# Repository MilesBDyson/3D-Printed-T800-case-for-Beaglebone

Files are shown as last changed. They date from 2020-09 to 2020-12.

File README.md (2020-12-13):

The STL files were originally downloaded from somewhere on Thingiverse. I used blender to modify them for
mounting a Beaglebone Black inside the head, I hand drilled 3 holse for the user leds in each temple,
the holse for the eyes are ruffly 3mm, so if you want to use the bigger 5mm LED's like i have you will
need to open them up.

the 4 hols between the top and middle pieces of the head are for pins so you can remove the top allowing access
to the Beaglebone, also there is room to moune a 50 x 50 x 15 12v fan wich will be activated by a relay

the bolt patern for the beaglebone was marked holding the Beaglebone in place, then installing 3/8 inch plastic
standoffs on the Beaglebone, I drilled the holes and dry fitted everything to be sure the standoffs fit nicely
(had to open up a few of them).

I applied a liberal amount of model glue to them and installed the Beaglebone, allowing several hours for the
glue to dry before removing the Beaglebone, I applied more glue making sure the standoffs were firmly fixed in
place.

This project is not perfect and it did require a lot of hand work to clean everything up nicely but my patience
payed off. How I moved the User LED's to GPIO pins is documented with a step by step guide as it was not for
the beginner and requires modifying and compiling a few files along with creating an overlay wich will free up
the pins to be used used. 

<b>Warining</b>: the user led's pins can not be used to light up a LED directly, you will damage your Beaglebone, You
will need to use an IC chip like ULN2003 to lite the LED's for you, also mentioned in the documents for moving
the User LED's to GPIO pins.

<b>Update:</b> i decided to holow out the eyes with a dremel and printed a translusent red lens to cover the LED's in the eyes.

Initial Print
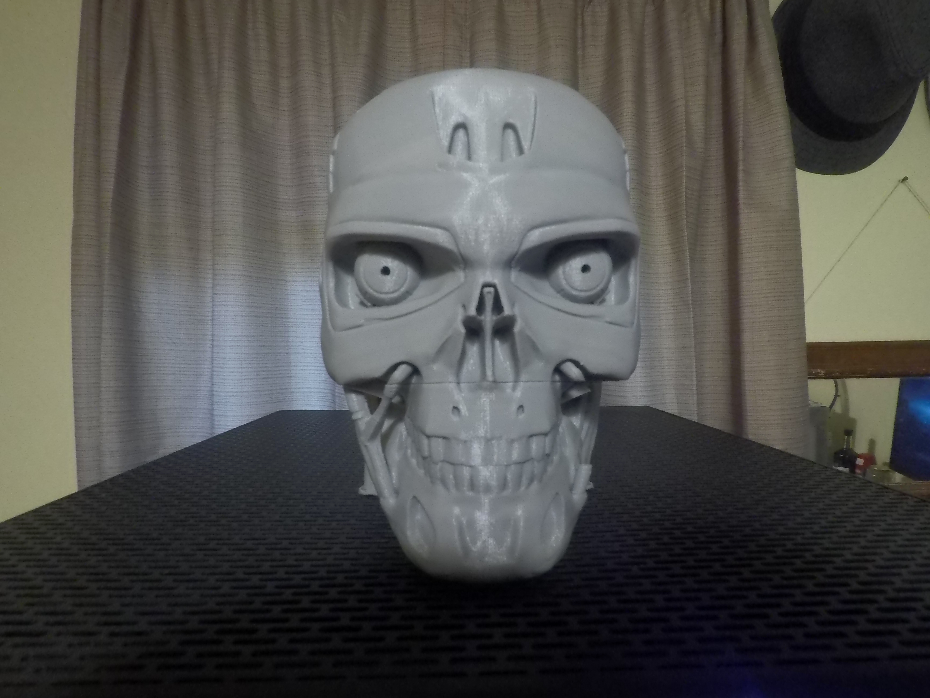
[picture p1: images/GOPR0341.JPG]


Chrome spaypaint (not relly chrome) for base color
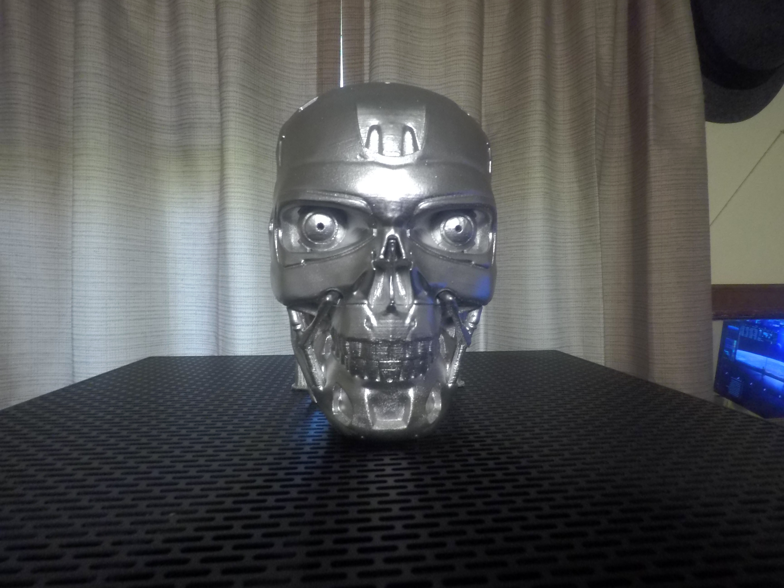
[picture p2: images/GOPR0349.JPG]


After Antiquing
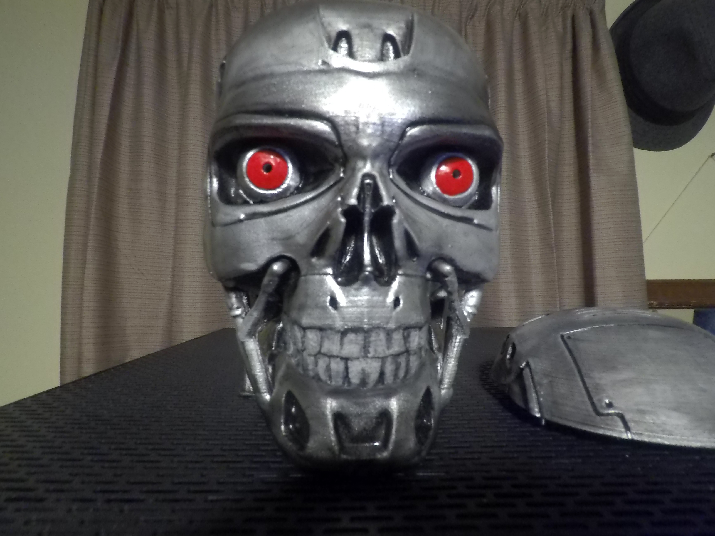
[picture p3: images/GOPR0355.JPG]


Close up of holes in the temples for User LEDS from the BBB
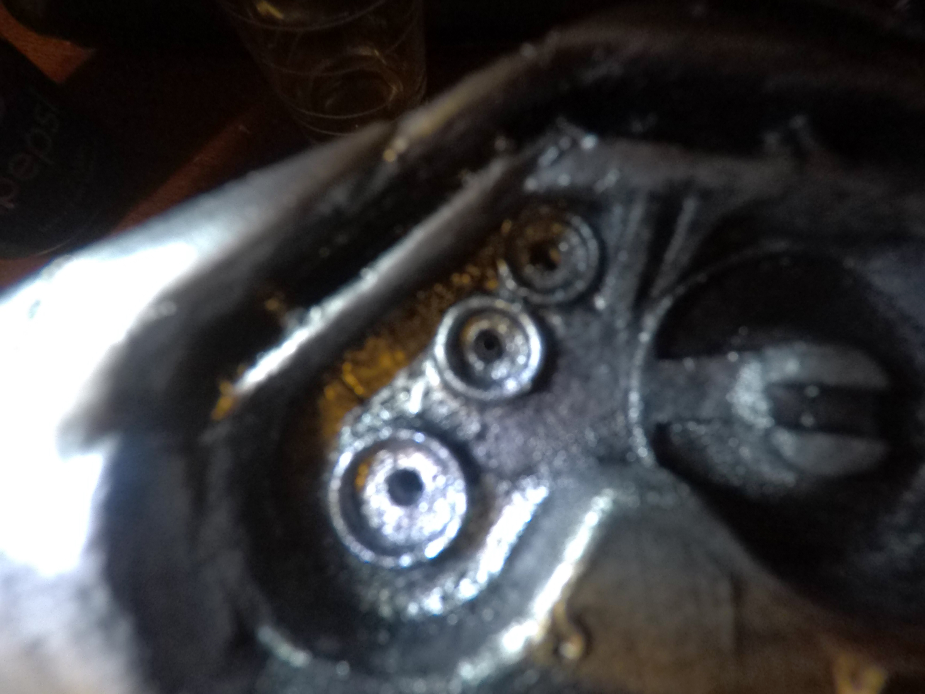
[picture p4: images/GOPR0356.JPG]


Beaglebone Mounted inside the head
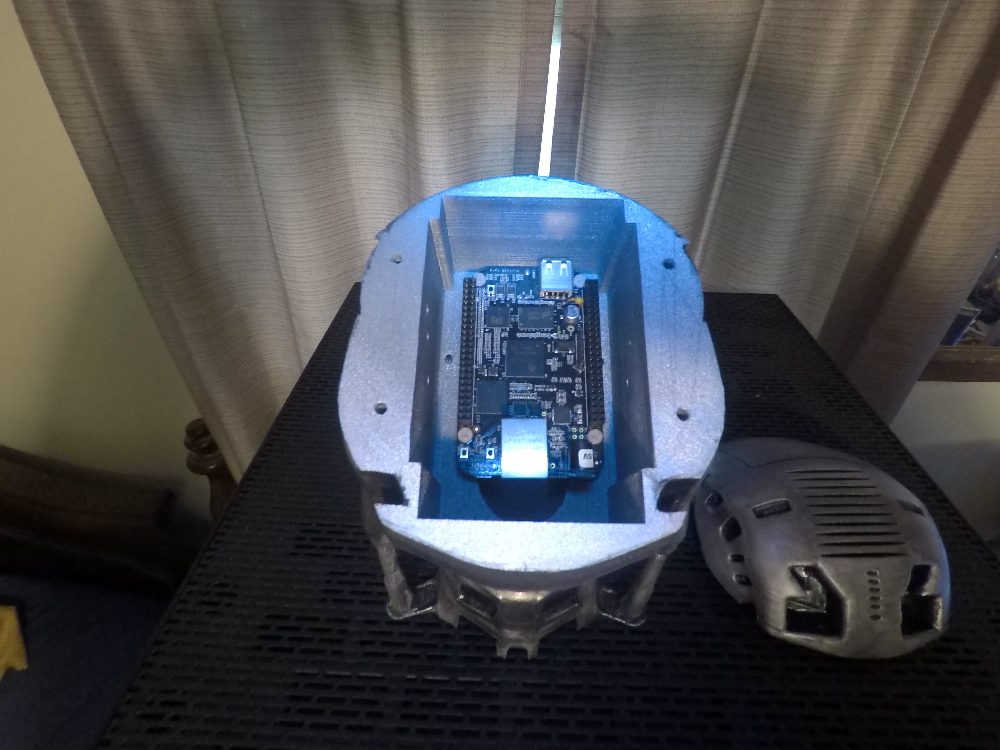
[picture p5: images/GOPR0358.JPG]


Finished result after modifying the eyss with translucent lenses
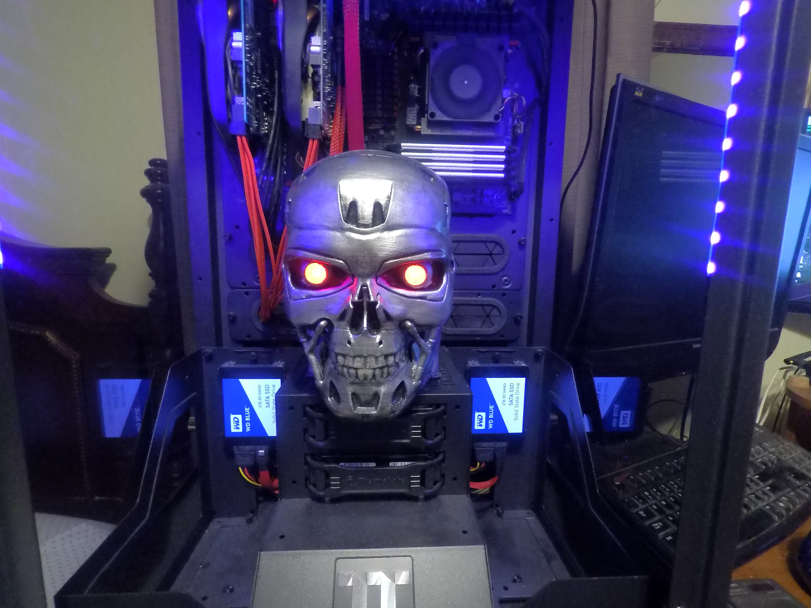
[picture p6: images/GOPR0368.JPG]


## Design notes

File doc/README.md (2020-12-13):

This folder contains instructions and a few charts on how i moved the User LED's to external pins on the Beaglebone Black to be mounted in the templs of the skull

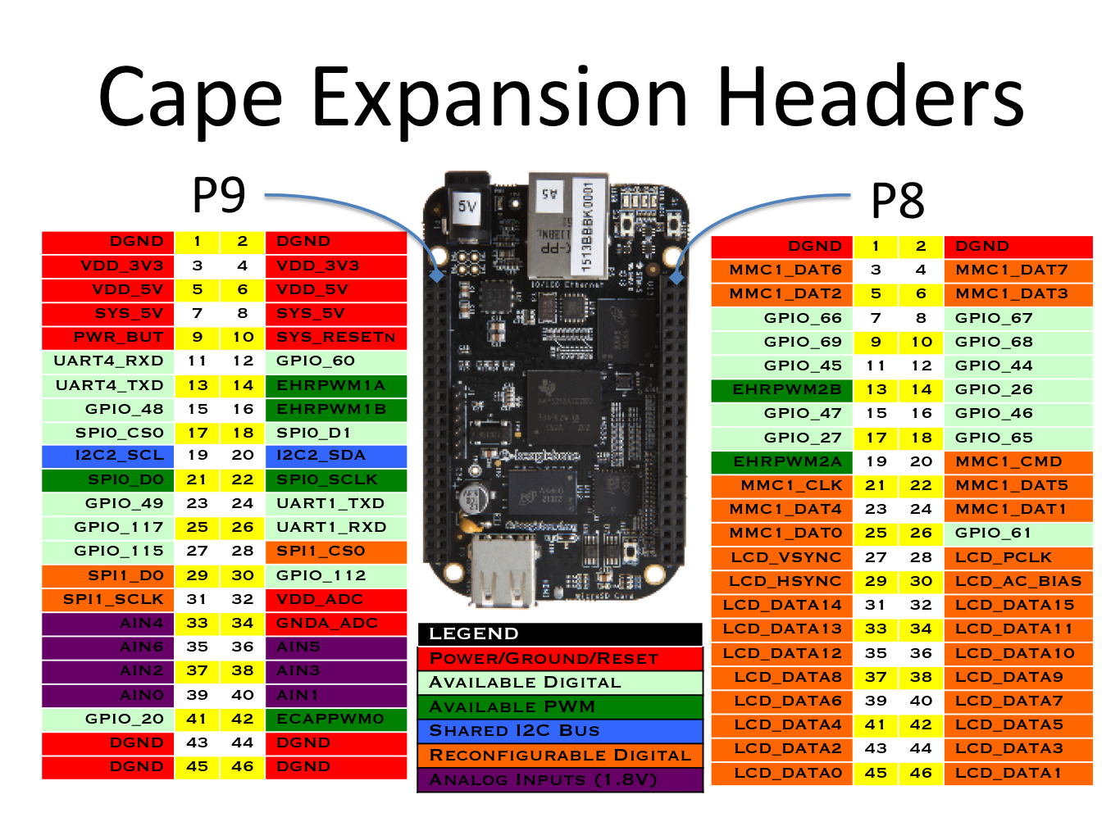
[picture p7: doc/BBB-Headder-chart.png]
T800


P8Header

P9Header

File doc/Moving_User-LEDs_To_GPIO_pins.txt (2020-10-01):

Remaping the User LED's to GPIO pins on the BeagleBone Black running Ubuntu Server 18.04 or Newer.

If you have not setup your Beaglebone Black Rev. C yet, you may want to refer to

https://rcn-ee.com/rootfs/2020-04-09/flasher/ 

This is the newest release at the time of writing this guide. for the latest Ubuntu Server Image you may want to check by navigating
up one level and make sure you are in the newest release directory where you can download and copy to your microSD card that you
can install directly to your onboard eMMC. This guide was only tested on Ubuntu but may be the same for Debian also availble there.

Wiring the circuit for the Leds.

Remember you should allways wire your circuit with the Beaglebone Powered Down. You may damage your Beaglebone if you attempt to
wire up a circuit with it powered ON.

you will need 4 leds with 4 470ohm resistors and 1 ULN2003A 16-pin Dip, a breadboard will be ideal for setting it all up as you
can get things working first then move the circuit as needed to a circuitboard to be soldered for a more perminant setup.

            ULN2003A                       LED                    Resistor
             __ __
   1    1B--|  U  |--1C    9
   2    2B--|     |--2C    10              ___
   3    3B--|     |--3C    11             |   |                   -------
   4    4B--|     |--4C    12             |   |          ---------| 470 |---------
   5    5B--|     |--5C    13            -------                  -------
   6    6B--|     |--6C    14              | |
   7    7B--|     |--7C    15              | | Neg
   8   GND--|_____|--VCC   16          Pos |  

Make your connections from your Beaglebone GPIO pins to the 'B' side of the ULN2003A IC chip.
Then make your connecitons from the ULN2003A IC Chip 'C' side to your LED's Negative side.

   --------------------------------------------
   | Headder | IC Pin |  IC  | IC Pin |  LED  |
   --------------------------------------------
   |  P8_8   |   1B   |      |   1C   |  Neg  |
   |  P8_10  |   2B   |      |   2C   |  Neg  |
   |  P8_12  |   3B   |      |   3C   |  Neg  |
   |  P8_14  |   4B   |      |   4C   |  Neg  |
   --------------------------------------------

Now i recommend using an external power source for most projects as to not worry about overloading the Beaglebone, so
if you do use an external power sourece be sure to share the ground of your Beaglebone with the power soruce or the
circuit will not work.

beaglebone ground ----------\
                             -----> IC Chip Ground (pin 8)                 
external power ground-------/

external power positive ------470ohm resistor-------Pos leg of LED

'C' side of IC Chip---------------------------------Neg leg of LED

Remaping the User LED's

1.) Make Backup
SSH into your Beaglebone and create a backup of the file your about to edit just in case, its allways best to have a backup.

$ sudo cp /opt/source/dtb-4.14-ti/src/arm/am335x-bone-common.dtsi /opt/source/dtb-4.14-ti/src/arm/am335x-bone-common.dtsi.backup

2.) remap user LED's to the GPIO pins
Edit the file to move the User LED's to the GPIO pins of your choice or you may use the same ones i did in this guide.

$ sudo nano /opt/source/dtb-4.14-ti/src/arm/am335x-bone-common.dtsi

make your file look similar to this, you will find this section near the top of the file, you will need to refer to the headder
tables, also included in the doc folder and get the mode7 (column) information, depending on what pins you choose. 

comment out with "//" the original lines and add new ones containing your pin information, incase you wish to undo this later.
I am using pins from the P8 Hedder pins 8,10,12 and 14

                led2 {
                        label = "beaglebone:green:usr0";
//                      gpios = <&gpio1 21 GPIO_ACTIVE_HIGH>;
                        gpios = <&gpio2 3 GPIO_ACTIVE_HIGH>;            /* P8_8  */
                        linux,default-trigger = "heartbeat";
                        default-state = "off";
                };

                led3 {
                        label = "beaglebone:green:usr1";
//                      gpios = <&gpio1 22 GPIO_ACTIVE_HIGH>;
                        gpios = <&gpio2 4 GPIO_ACTIVE_HIGH>;            /* P8_10 */
                        linux,default-trigger = "mmc0";
                        default-state = "off";
                };

                led4 {
                        label = "beaglebone:green:usr2";
//                      gpios = <&gpio1 23 GPIO_ACTIVE_HIGH>;
                        gpios = <&gpio1 12 GPIO_ACTIVE_HIGH>;           /* P8_12 */
                        linux,default-trigger = "cpu0";
                        default-state = "off";
                };

                led5 {
                        label = "beaglebone:green:usr3";
//                      gpios = <&gpio1 24 GPIO_ACTIVE_HIGH>;
                        gpios = <&gpio0 26 GPIO_ACTIVE_HIGH>;           /* P8_14 */
                        linux,default-trigger = "mmc1";
                        default-state = "off";
                };

refer to the header tables for correct address/offset (column) of the pins you are using, this will be a Hexadecimal number.

        user_leds_s0: user_leds_s0 {
                pinctrl-single,pins = <
//                      AM33XX_PADCONF(AM335X_PIN_GPMC_A5, PIN_OUTPUT_PULLDOWN, MUX_MODE7)      /* gpmc_a5.gpio1_21 */
//                      AM33XX_PADCONF(AM335X_PIN_GPMC_A6, PIN_OUTPUT_PULLUP, MUX_MODE7)        /* gpmc_a6.gpio1_22 */
//                      AM33XX_PADCONF(AM335X_PIN_GPMC_A7, PIN_OUTPUT_PULLDOWN, MUX_MODE7)      /* gpmc_a7.gpio1_23 */
//                      AM33XX_PADCONF(AM335X_PIN_GPMC_A8, PIN_OUTPUT_PULLUP, MUX_MODE7)        /* gpmc_a8.gpio1_24 */
                        AM33XX_PADCONF(0x894, PIN_OUTPUT_PULLDOWN, MUX_MODE7)      /* P8_8  */
                        AM33XX_PADCONF(0x898, PIN_OUTPUT_PULLUP, MUX_MODE7)        /* P8_10 */
                        AM33XX_PADCONF(0x830, PIN_OUTPUT_PULLDOWN, MUX_MODE7)      /* P8_12 */
                        AM33XX_PADCONF(0x828, PIN_OUTPUT_PULLUP, MUX_MODE7)        /* P8_14 */

                >;
        };

save and close nano (CTRL+o) to save and (CTRL+x) to close.

3.) Enter directory to build the new files

$ cd /opt/source/dtb-4.14-ti/

$ sudo make clean
$ sudo make
$ sudo make install

4.) Create an overlay for the pins.
This will make a new file so it will be blank.

$ sudo nano /opt/source/bb.org-overlays/src/arm/BB-BONE-MOVED-USER-LEDS.dts

copy the info below and paste it into your terminal, dont forget to change the pins if you used different ones.

/* /opt/source/bb.org-overlays/src/arm/BB-BONE-MOVED-USER-LEDS.dts */

/dts-v1/;
/plugin/;

/ {
        compatible = "ti,beaglebone-black";

        /* identification */
        part-number = "BB-BONE-MOVED-USER-LEDS";
        version = "00A0";

        /*
         * Free up the pins to be used by the USER LED's from the pinmux helpers.
         */
        fragment@0 {
                target = <&ocp>;
                __overlay__ {
                        P8_08_pinmux { status = "disabled"; };   /* P8_8:  Moved User LED's USER1 Heartbeat */
                        P8_10_pinmux { status = "disabled"; };   /* P8_10: Moved User LED's USER2 Sd Card   */
                        P8_12_pinmux { status = "disabled"; };   /* P8_12: Moved User LED's USER3 Kernel    */
                        P8_14_pinmux { status = "Disabled"; };   /* P8_14: Moved User LED's USER3 eMMC      */
                };
        };

};

5.) Change directory

$ cd /opt/source/bb.org-overlays

6.) Make
now you need to compile the new overlay so it can be used.

$ sudo make -d src/arm/BB-BONE-MOVED-USER-LEDS.dtbo

7.) Install
this will install the overlay to the correct directory as a .dtbo file.

$ sudo ./install.sh

8.) Edit uEnv.txt
Now we need to tell the Beaglebone where to find the overlay

$ sudo nano /boot/uEnv.txt

add the below line to the ###Custom Cape section of the uEnv.txt file

dtb_overlay=/lib/firmware/BB-BONE-MOVED-USER-LEDS.dtbo

OPTIONAL:
you may also want to uncomment thease
this will disable the video and audio to allow for more pins to be free

disable_uboot_overlay_video=1
disable_uboot_overlay_audio=1

save and close the file.

9.) reboot and cross fingers.....
once your Beaglebone reboots you should now see the LED's on your bread board behaving the same as the onboard
User-LED's use to, also the onboard User-LED's will no longer light up.

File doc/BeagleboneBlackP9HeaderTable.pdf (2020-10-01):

# Beaglebone Black P9 Header

Head_pin | $PINS | ADDR/OFFSET | Name | GPIO NO. | Mode7 | Mode6 | Mode5 | Mode4 | Mode3 | Mode2 | Mode1 | Mode0 | PIN | Notes
P9_01 | | | GND | | | | | | | | | | | Ground
P9_02 | | | GND | | | | | | | | | | | Ground
P9_03 | | | DC_3.3V | | | | | | | | | | | 250mA Max Current
P9_04 | | | DC_3.3V | | | | | | | | | | | 250mA Max Current
P9_05 | | | VDD_5V | | | | | | | | | | | 1A Max Current (only if DC jack powered)
P9_06 | | | VDD_5V | | | | | | | | | | | 1A Max Current (only if DC jack powered)
P9_07 | | | SYS_5V | | | | | | | | | | | 250mA Max Current
P9_08 | | | SYS_5V | | | | | | | | | | | 250mA Max Current
P9_09 | | | PWR_BUT | | | | | | | | | | | Has a 5V Level (pulled up by TPS65217C)
P9_10 | | | SYS_RESETn | | | | | | | | | RESET_OUT | A10
P9_11 | 28 | 0x870/070 | UART4_RXD | 30 | gpio0[30] | uart4_rxd_mux2 | | mmc1_sdcd | rmii2_crs_dv | gpmc_csn4 | mii2_crs | gpmc_wait0 | T17 | NB: GPIOs limit current to 4-6mA output
P9_12 | 30 | 0x878/078 | GPIO1_28 | 60 | gpio1[28] | mcasp0_aclkr_mux3 | | gpmc_dir | mmc2_dat3 | gpmc_csn6 | mii2_col | gpmc_be1n | U18 | and approx. 8mA on input.
P9_13 | 29 | 0x874/074 | UART4_TXD | 31 | gpio0[31] | uart4_txd_mux2 | | mmc2_sdcd | rmii2_rxerr | gpmc_csn5 | mii2_rxerr | gpmc_wpn | U17
P9_14 | 18 | 0x848/048 | EHRPWM1A | 50 | gpio1[18] | ehrpwm1A_mux1 | | gpmc_a18 | mmc2_dat1 | rgmii2_td3 | mii2_txd3 | gpmc_a2 | U14
P9_15 | 16 | 0x840/040 | GPIO1_16 | 48 | gpio1[16] | ehrpwm1_tripzone_input | | gpmc_a16 | mii2_txen | rmii2_tctl | gmii2_txen | gpmc_a0 | R13
P9_16 | 19 | 0x84c/04c | EHRPWM1B | 51 | gpio1[19] | ehrpwm1B_mux1 | | gpmc_a19 | mmc2_dat2 | rgmii2_td2 | mii2_txd2 | gpmc_a3 | T14
P9_17 87 0x95c/15c I2C1_SCL 5 gpio0[5] | pr1_uart0_txd | ehrpwm0_synci I2C1_SCL mmc2_sdwp spi0_cs0 A16
P9_18 86 0x958/158 I2C1_SDA 4 gpio0[4] | pr1_uart0_rxd | ehrpwm0_tripzone I2C1_SDA mmc1_sdwp spi0_d1 B16
P9_19 | 95 | 0x97c/17c I2C2_SCL | 13 | gpio0[13] | pr1_uart0_rts_n | spi1_cs1 I2C2_SCL dcan0_rx timer5 uart1_rtsn D17 | Allocated (Group: pinmux_i2c2_pins)
P9_20 | 94 | 0x978/178 I2C2_SDA | 12 | gpio0[12] | pr1_uart0_cts_n | spi1_cs0 I2C2_SDA dcan0_tx timer6 uart1_ctsn D18 | Allocated (Group: pinmux_i2c2_pins)
P9_21 85 0x954/154 UART2_TXD 3 gpio0[3] EMU3_mux1 | pr1_uart0_rts_n | ehrpwm0B I2C2_SCL uart2_txd spi0_d0 B17
P9_22 84 0x950/150 UART2_RXD 2 gpio0[2] EMU2_mux1 | pr1_uart0_cts_n | ehrpwm0A I2C2_SDA uart2_rxd spi0_sclk A17
P9_23 | 17 | 0x844/044 | GPIO1_17 | 49 | gpio1[17] | ehrpwm0_synco | gpmc_a17 | mmc2_dat0 | rgmii2_rxdv | gmii2_rxdv | gpmc_a1 | V14
P9_24 97 0x984/184 UART1_TXD 15 gpio0[15] | pr1_pru0_pru_r31_16 | pr1_uart0_txd | I2C1_SCL dcan1_rx mmc2_sdwp uart1_txd D15
P9_25 | 107 | 0x9ac/1ac GPIO3_21 | 117 | gpio3[21] | pr1_pru0_pru_r31_7 pr1_pru0_pru_r30_7 | EMU4_mux2 mcasp1_axr1 mcasp0_axr3 eQEP0_strobe mcasp0_ahclkx A14 | Allocated (Group: mcasp0_pins)
P9_26 96 0x980/180 UART1_RXD 14 gpio0[14] | pr1_pru1_pru_r31_16 | pr1_uart0_rxd | I2C1_SDA dcan1_tx mmc1_sdwp uart1_rxd D16
P9_27 105 0x9a4/1a4 GPIO3_19 115 gpio3[19] | pr1_pru0_pru_r31_5 pr1_pru0_pru_r30_5 | | EMU2_mux2 mcasp1_fsx mcasp0_axr3 eQEP0B_in mcasp0_fsr C13
P9_28 | 103 | 0x99c/19c SPI1_CS0 | 113 | gpio3[17] | pr1_pru0_pru_r31_3 pr1_pru0_pru_r30_3 | eCAP2_in_PWM2_out spi1_cs0 mcasp0_axr2 ehrpwm0_synci mcasp0_ahclkr C12 | Allocated (Group: mcasp0_pins)
P9_29 | 101 | 0x994/194 SPI1_D0 | 111 | gpio3[15] | pr1_pru0_pru_r31_1 pr1_pru0_pru_r30_1 | mmc1_sdcd_mux1 spi1_d0 ehrpwm0B mcasp0_fsx B13 | Allocated (Group: mcasp0_pins)
P9_30 | 102 | 0x998/198 SPI1_D1 | 112 | gpio3[16] | pr1_pru0_pru_r31_2 pr1_pru0_pru_r30_2 | mmc2_sdcd_mux1 spi1_d1 ehrpwm0_tripzone mcasp0_axr0 D12 | Allocated? Mcasp0_pins? Check…
P9_31 | 100 | 0x990/190 SPI1_SCLK | 110 | gpio3[14] | pr1_pru0_pru_r31_0 pr1_pru0_pru_r30_0 | mmc0_sdcd_mux1 spi1_sclk ehrpwm0A mcasp0_aclkx A13 | Allocated (Group: mcasp0_pins)
P9_32 | VADC | | Voltage Reference for ADC (NB: 1.8V)
P9_33 | AIN4 | C8 | NB: 1.8V tolerant
P9_34 | AGND | | Ground for ADC
P9_35 | AIN6 | A8 | NB: 1.8V tolerant
P9_36 | AIN5 | B8 | NB: 1.8V tolerant
P9_37 | AIN2 | B7 | NB: 1.8V tolerant
P9_38 | AIN3 | A7 | NB: 1.8V tolerant
P9_39 | AIN0 | B6 | NB: 1.8V tolerant
P9_40 | AIN1 | C7 | NB: 1.8V tolerant
P9_41A 109 0x9b4/1b4 CLKOUT2 20 gpio0[20] EMU3_mux0 | pr1_pru0_pru_r31_16 | timer7_mux1 clkout2 tclkin xdma_event_intr1 D14 Both signals are connected to P21 of P11
P9_41B 0x9a8/1a8 GPIO3_20 116 gpio3[20] | pr1_pru0_pru_r31_6 pr1_pru0_pru_r30_6 | emu3 Mcasp1_axr0 eQEP0_index mcasp0_axr1 D13 Both signals are connected to P21 of P11
P9_42A | 89 | 0x964/164 | GPIO0_7 | 7 | gpio0[7] | xdma_event_intr2 | mmc0_sdwp | spi1_sclk | pr1_ecap0_ecap_capin_apwm_o | spi1_cs1 | uart3_txd | eCAP0_in_PWM0_out | C18 | Both signals are connected to P22 of P11
P9_42B | | 0x9a0/1a0 | GPIO3_18 | 114 | gpio3[18] | pr1_pru0_pru_r31_4 | pr1_pru0_pru_r30_4 | | Mcasp1_aclkx | Mcaspo_axr2 | eQEP0A_in | Mcasp0_aclkr | B12 | Both signals are connected to P22 of P11
| | | | | | | | | | | | | | Allocated (Group:mcasp0_pins)
P9_43 | | | GND | | | | | | | | | | | - See Pg.50 of the SRM
P9_44 | | | GND | | | | | | | | | | | Ground
P9_45 | | | GND | | | | | | | | | | | Ground
P9_46 | | | GND | | | | | | | | | | | Ground
| | | | | | | | | | | | | | For updates see: www.derekmolloy.ie
P9 Header | cat $PINS | ADDR + | Name | GPIO NO. | Mode 7 | | | | | | Mode 1 | Mode 0 | CPU | Notes
| Allocated | 44e10000 | | (Mode 7) | | | | GPIO Settings | | | | | | Please e-mail me directly at:
| | Offset from: | | | | Bit 6 | Bit 5 | Bit 4 | Bit 3 | Bit 2,1,0 | | | | derek@derekmolloy.ie
| | 44e10800 | | | | Slew Control | Receiver Active | Pullup/Pulldown | Enable Pullup/Pulldown | Mux Mode | | | | if you notice a mistake
| | | | | | 0 Fast | 0 Disable | 0 Pulldown select | 0 Enabled | 000 Mode 0 to | | | | Thanks Frank for the PRU work!
| | | | | | 1 Slow | 1 Enable | 1 Pullup select | 1 Disabled | 111 Mode 7

e.g. OUTPUT GPIO(mode7) 0x07 pulldown, 0x17 pullup, 0x?f no pullup/down e.g. INPUT GPIO(mode7) 0x27 pulldown, 0x37 pullup, 0x?f no pullup/down

www.derekmolloy.ie

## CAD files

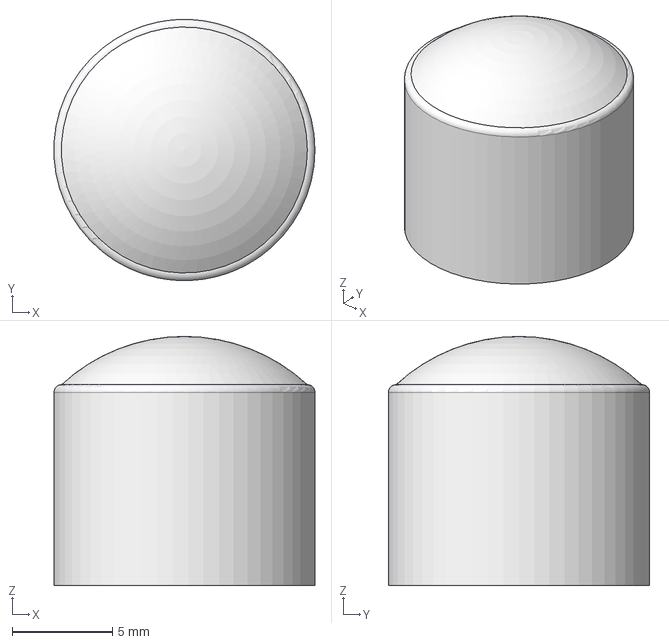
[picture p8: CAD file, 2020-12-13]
led-eye.FCStd
13.0 x 13.0 x 12.4 mm

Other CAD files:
led-eye.stl
